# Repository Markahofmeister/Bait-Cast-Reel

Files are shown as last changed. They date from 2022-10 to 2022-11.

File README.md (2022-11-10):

# Bait-Cast-Reel

### A fishing-inspired spinoff of the original "Bop-It" Toy, completed for the University of Pittsburgh's ECE1895: Junior Design Course. 

File Structure: 
- `Bait-Cast-Reel-PCB` - Altium schematics and pcb desdign files for a 4-layered PCB
- `Bait-Cast-Reel-PCB-2l` - Altium schematics and pcb desdign files for a 2-layered PCB
- `diagrams-datasheets` - reference datasheets and pinout diagrams
- `fab` - .stl files of things to print/laser cut and PCB .step model
- `media` - images of the design process
- `software` - main src and supplementary testing sketches

The toy is shaped like a fishing rod and randomly selects one of three user inputs, which the user must complete within the allocated time window, else the user will lose the game. The three tangible user inputs - "Bait," "Cast," and "Reel," - use 3 different transducers to determine whether or not the user input was successful. 

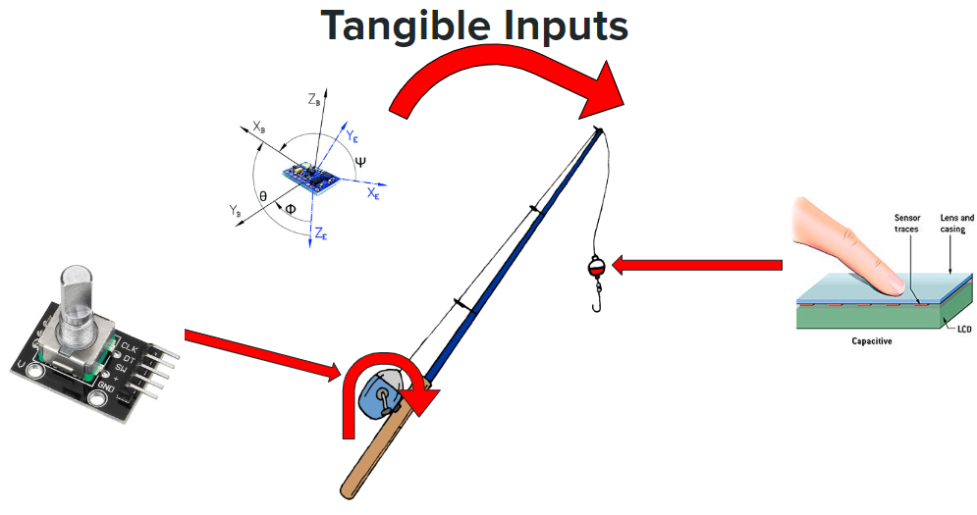
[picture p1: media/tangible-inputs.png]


## Firmware Flow

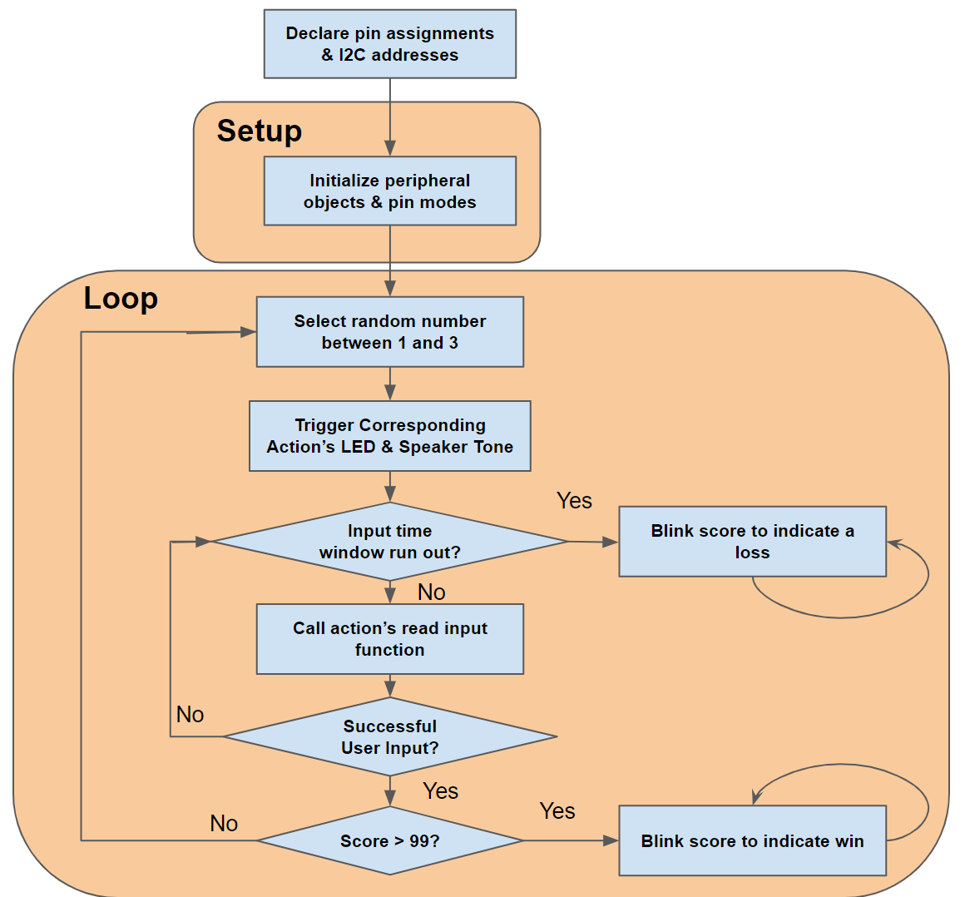
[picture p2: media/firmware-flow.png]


## System Diagram 

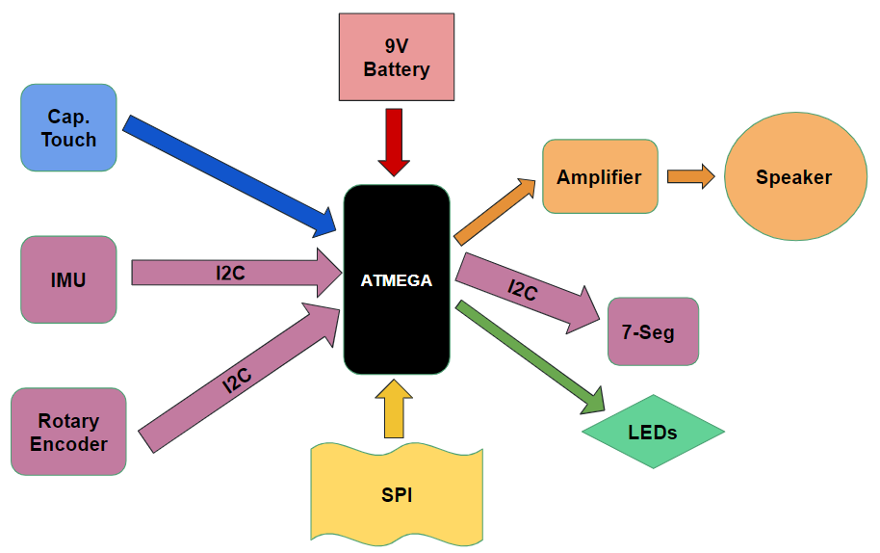
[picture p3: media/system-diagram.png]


## PCB

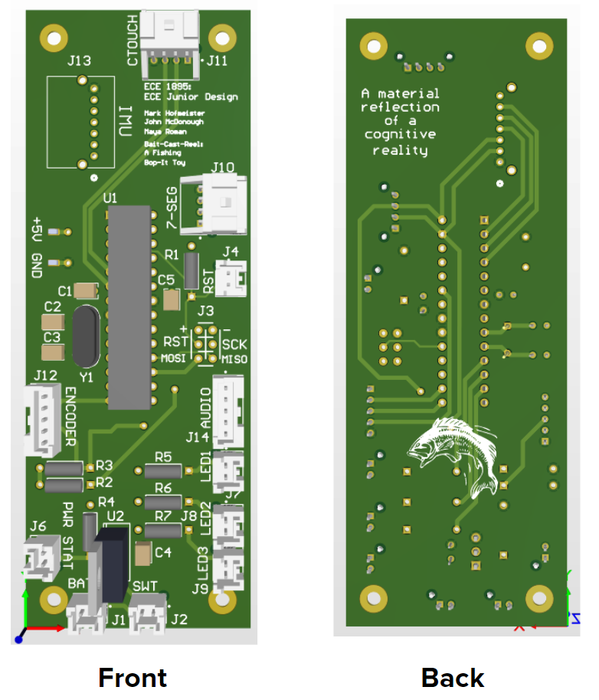
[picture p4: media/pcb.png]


## Enclosure 

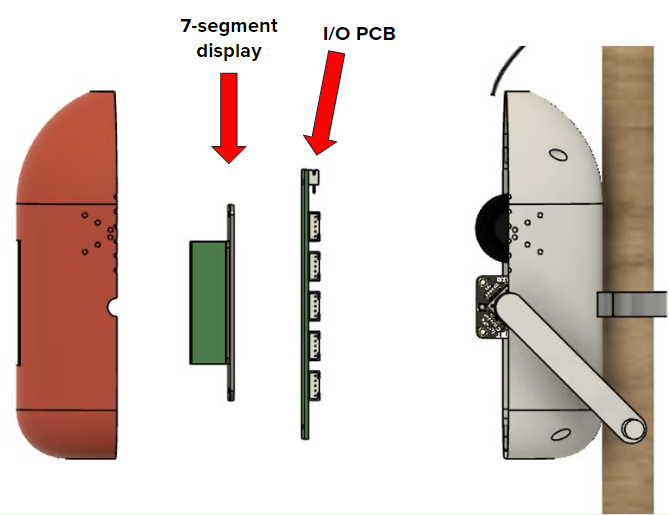
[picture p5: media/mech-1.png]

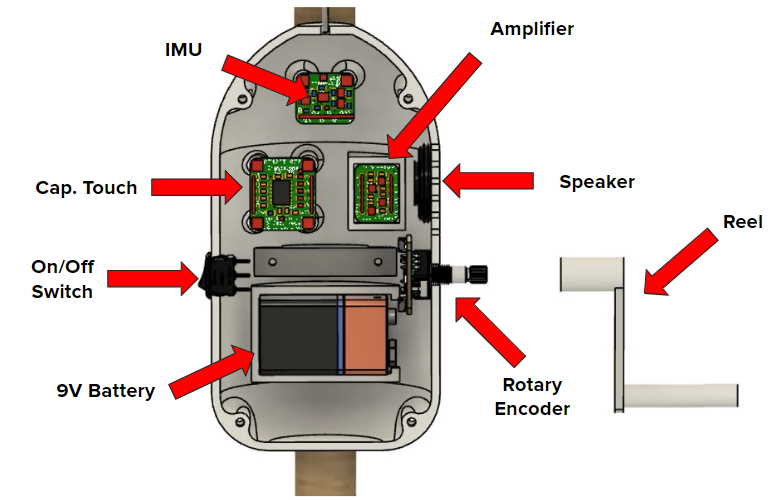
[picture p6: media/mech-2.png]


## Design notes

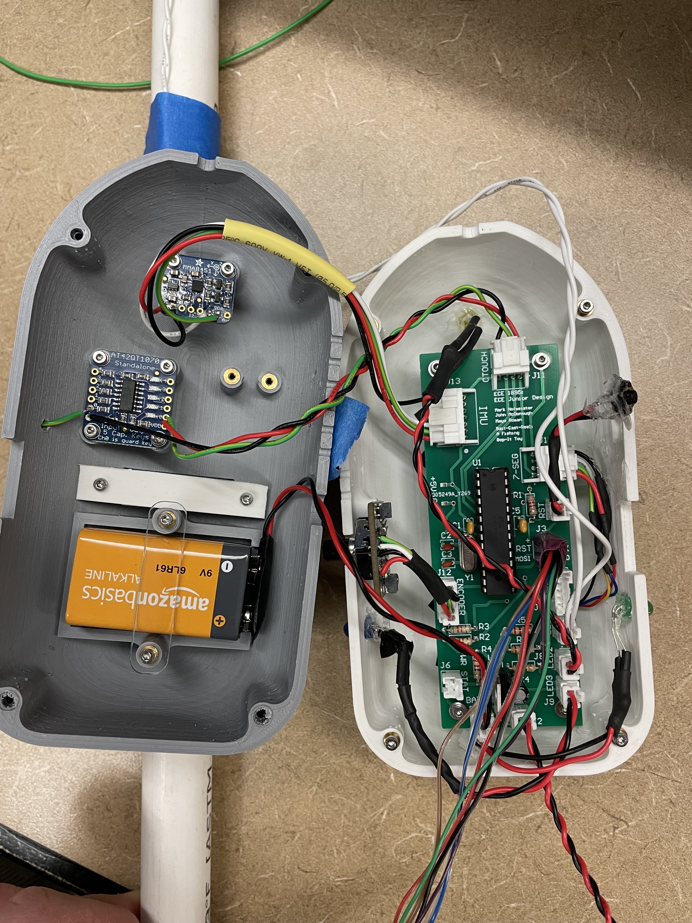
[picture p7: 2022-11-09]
media/enclosure-real.jpg

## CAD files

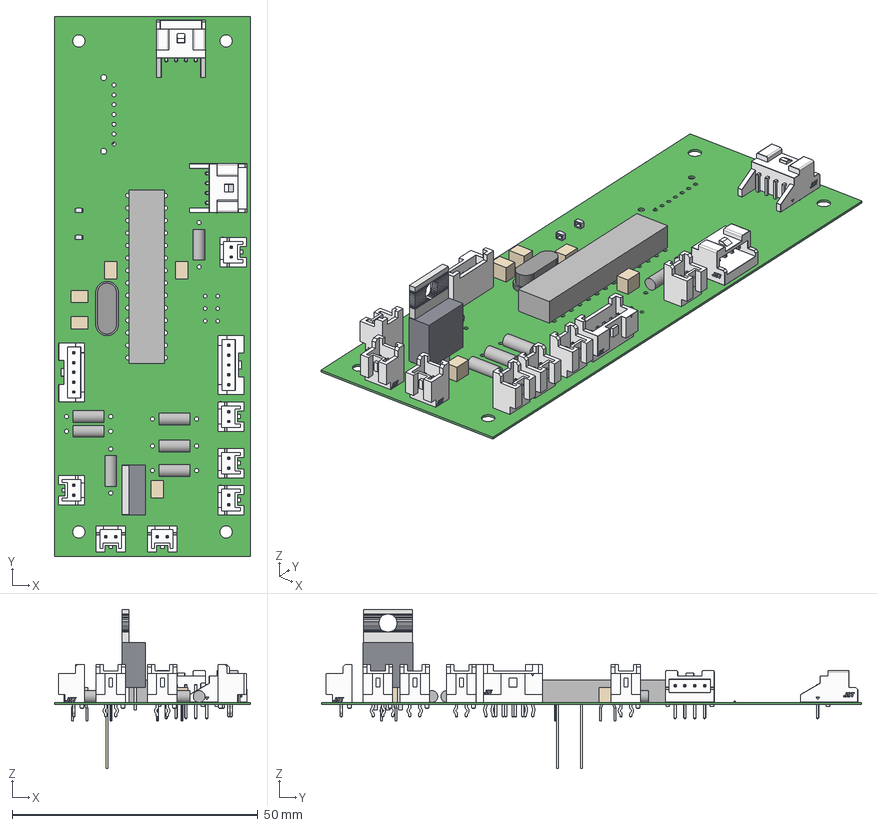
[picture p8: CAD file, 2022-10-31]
fab/main-IO-pcb.step
40.0 x 110.0 x 32.4 mm
terminal x 2
logo x 2
Extruded x 45
Pin1_Triangle x 2
JST x 2
B02B-PASK-1 x 7

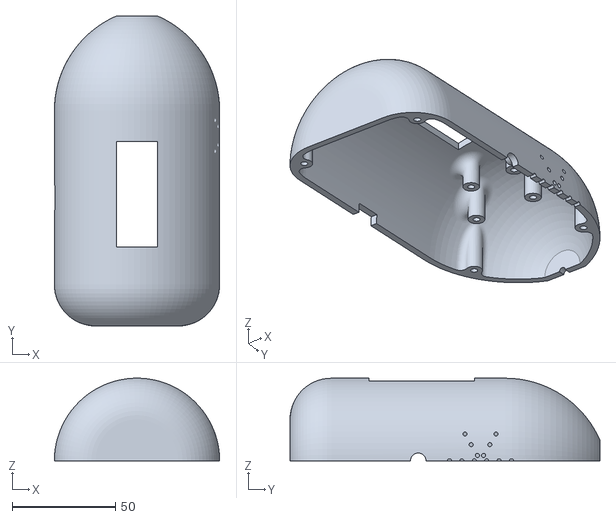
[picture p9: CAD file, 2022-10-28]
fab/mainboard_side.stl
80.0 x 150.0 x 40.0

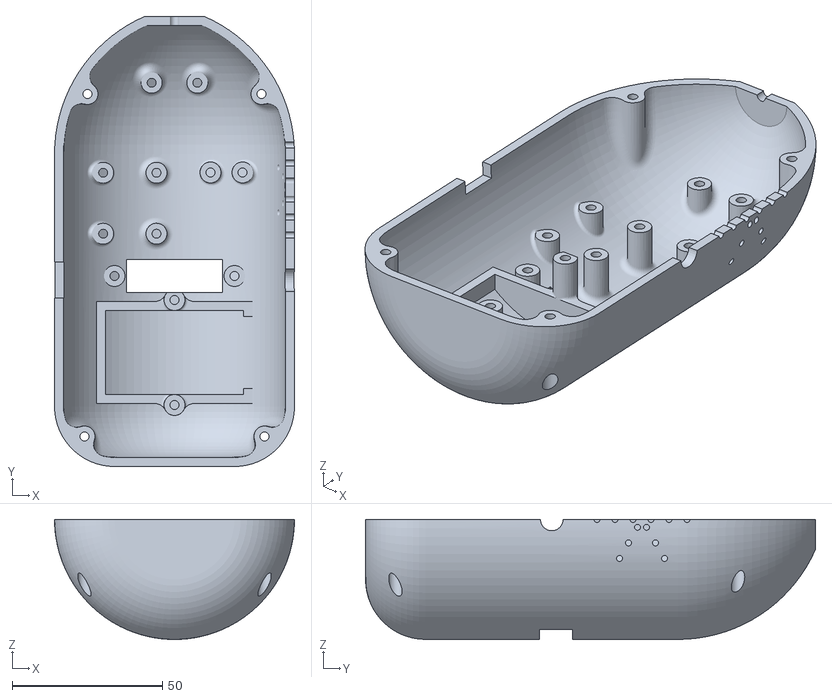
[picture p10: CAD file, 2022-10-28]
fab/battery_side.stl
80.0 x 150.0 x 40.0

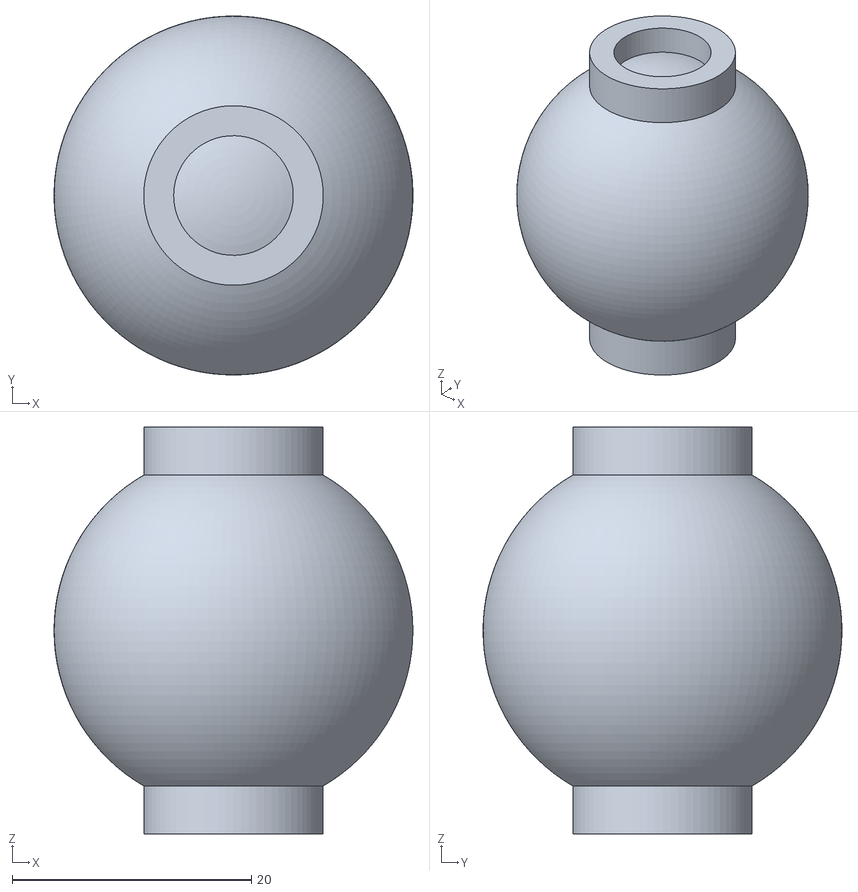
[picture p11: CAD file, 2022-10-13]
fab/Bobber.stl
30.0 x 30.0 x 34.0

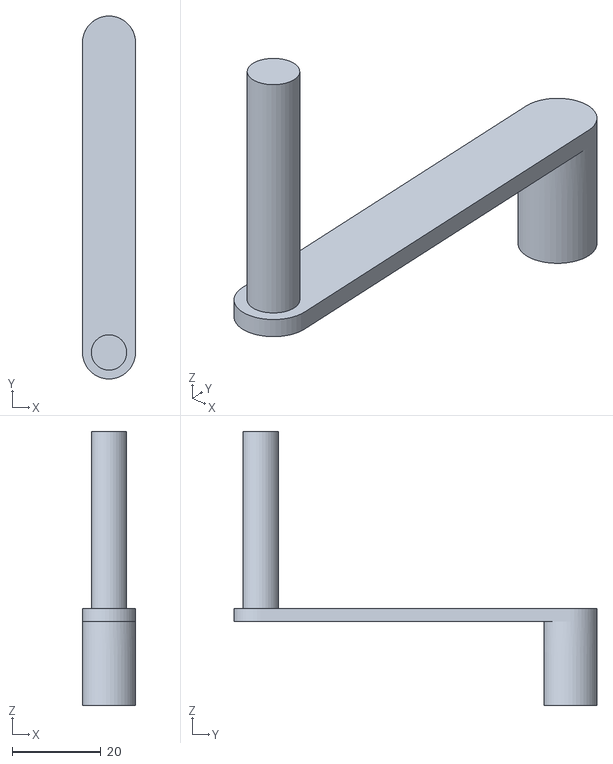
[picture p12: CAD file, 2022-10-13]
fab/crank.stl
12.0 x 82.0 x 62.0

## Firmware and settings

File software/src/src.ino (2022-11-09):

/**
 * File Name: src.ino 
 * Author: Mark Hofmeister, Maya Román, John McDonough
 * Created: 10/25/2022
 * Last Modified: 11/7/2022
 * 
 * Source code uploaded to Bait-Cast-Reel ATMEGA328p.
 */
 
#include "Adafruit_seesaw.h"            //Seesaw library, used for function calls to interact with encoder
#include <Adafruit_LEDBackpack.h>       //Used to communicate I2C to Adafruit's "backpack" for 7-seg display. 
#include <Adafruit_Sensor.h>
#include <Adafruit_MMA8451.h>
#include <math.h>

 /*
  * Define cap-touch global variables 
  */
    #define capTouchInput 3               //pin 5
    #define capTouchLED 5                 //pin 11
    
/*
 * Define IMU global variables & object
 */
    #define IMULED 6
    Adafruit_MMA8451 IMU = Adafruit_MMA8451();

/*
 * Define encoder global variables/object 
 */
    #define ENCODER_ADDR 0x36               //define I2C address of encoder as 0x36 
     
    #define SS_SWITCH 24                    //Not yet sure what this is required for
    //#define SS_NEOPIX 6                     //Required for the neopixel on the encoder board

    #define encoderLED 7
    
    Adafruit_seesaw encoder;                //Initialize encoder object and an integer to assign the position to 
    
    int32_t encoderPos = 0;                 //variable to store position, initialized to 0;
    int32_t lastPos = 0;                    //variable to store position from last encoder measurement, initialized to 0;
    int32_t lastFullRot = 0;                //variable to store to encoder position when it crosses the full rotation threshold
    int8_t fullTurn = 24;                   //One full rotation of the encoder is 24 steps. 

/*
 * Define 7-seg global variables & object
 */
    #define SEVSEG_ADDR 0x70                //define global I2C address of 7seg backpack 
    Adafruit_7segment sevSeg = Adafruit_7segment();   //initialize sevSeg object to interact with I2C backpack 
    int scoreCount = 0;                               //score to display and increment as user successfully inputs
  
  int inputWindow = 5000;                  //Start the input window length at 1000ms, which is the time allowed for a user input. Decreases with every iteration. 
  int inputWindowDec = 5;                  //integer to decrement the inputWindow by each iteration 

  /**
   * Define Audio global variables/pins
   */
   #define audioOut 9
   #define audioOut_LOW 10
   #define baitFreq 100
   #define castFreq 200
   #define reelFreq 300
   uint8_t audioDuration = 2000;   

void setup() {

  /*
   * Initialize cap. touch Pins
  */
      pinMode(capTouchInput, INPUT);
      pinMode(capTouchLED, OUTPUT);

  /*
   * Initialize IMU object & interrupts
  */
      pinMode(IMULED, OUTPUT);
      if(!IMU.begin()) {
        while(1);
      }
      IMU.setRange(MMA8451_RANGE_4_G);
 
  
  /*
   * Initialize encoder object & interrupts
  */
      Serial.println("Looking for encoder object");
      if (!encoder.begin(ENCODER_ADDR)) {
        Serial.println("Couldn't find encoder on default address, trying again.");
        while(1) delay(10);
      }
    
      encoder.pinMode(SS_SWITCH, INPUT_PULLUP);     //Is this pullup pin native to the encoder module itself? Will a bare ATMEGA vs. Uno have problems with this?
      encoderPos =  encoder.getEncoderPosition();
 
      pinMode(encoderLED, OUTPUT);

  /*
   * Initialize 7-seg object 
  */
      sevSeg.begin(SEVSEG_ADDR);
      sevSeg.print(scoreCount);
      sevSeg.writeDisplay();

  /**
   * Initialize audio pins
   */
      pinMode(audioOut, OUTPUT);
      pinMode(audioOut_LOW, OUTPUT);
      digitalWrite(audioOut_LOW, LOW);
  /**
   * Check LEDs and audio
   */
      digitalWrite(capTouchLED,HIGH); 
      digitalWrite(encoderLED,HIGH); 
      digitalWrite(IMULED,HIGH); 
//      tone(audioOut, baitFreq, audioDuration);
//      delay(audioDuration);
//      tone(audioOut, castFreq, audioDuration);
//      delay(audioDuration);
//      tone(audioOut, reelFreq, audioDuration);
      delay(2000);
      digitalWrite(capTouchLED,LOW); 
      digitalWrite(encoderLED,LOW); 
      digitalWrite(IMULED,LOW); 
}

void loop() {

  /*
   * Random number generation:
   * 1 - Bait - calls readBait() function
   * 2 - Cast - calls readCast() function
   * 3 - Reel - calls readReel() function
   */
  int randomNumber = floor(random(1,4));           //generates a random number in the range of 1 to 3  
   if(randomNumber == 1){
      //call cap_touch function
      digitalWrite(capTouchLED,HIGH);              // associated LED turns on 
      tone(audioOut, baitFreq, audioDuration);    //Play associated tone 
      delay(audioDuration);
      //send out audio command via talkie
      bool success_val = false;
      unsigned int current_time = millis(); //gets the number of milliseconds that program has been running

      while((millis()-current_time) <= inputWindow){//differencing time to see amount of time passed 
          success_val = readCapTouch();

          if(success_val){
            break;
          }
      }

      digitalWrite(capTouchLED, LOW); //turn LED off
      seven_seg(success_val);                              //Increment counter and display    
   } // end captouch if statement
   else if(randomNumber == 2){             //Cast It
      
      digitalWrite(IMULED, HIGH);

      tone(audioOut, castFreq, audioDuration);            //Play associated tone
      delay(audioDuration);
      unsigned int current_time2 = millis();
      bool success_val2 = false;

      while((millis()-current_time2) <= inputWindow){

        success_val2 = readIMU();
        
        if(success_val2){
          break;
        }
      }

      digitalWrite(IMULED, LOW);//turn off indicator led  
      seven_seg(success_val2);//Increment counter  
    } // end cast else if
    else if(randomNumber == 3){             //Reel It 
      
      digitalWrite(encoderLED, HIGH);
      tone(audioOut, reelFreq, audioDuration);          //Play associated tone
      delay(audioDuration);
      unsigned long current_time3 = millis();
      bool success_val3 = false;

      while((millis()-current_time3) <= inputWindow){
        success_val3 = readReel();

        if(success_val3){
          break;
        }
      }

      digitalWrite(encoderLED, LOW); //turn off indicator led  
      seven_seg(success_val3);      //Increment counter  
    } // end reel else if
      
    //default:            //Should never reach default, but you know. 
    else{
      while(1){
      }
    }

  inputWindow -= inputWindowDec;                  //Decrement inputWindow by inputWindowDec value (ms)
  
  delay(500);                                     //Delay 100ms before generating a new random action
}


/* readCapTouch()
 * Params: None
 * Retrns: Bool indicating whether the cap. touch was triggered
 * 
 */
bool readCapTouch(){
  int compare = 0;
  bool capOut; 
  
  while(compare < 1000){                
    if(digitalRead(capTouchInput) == LOW){
      capOut = true; 
    }else if(digitalRead(capTouchInput) == HIGH){
      capOut = false; 
      break;
    }
    delay(1);
    compare ++;
  }
  return capOut;
}

/* readReel()
 * Params: None
 * Retrns: Bool indicating whether the encoder was rotated one full rotation
 * 
 * Function to determine if the encoder was rotated through one full rotation since the last full rotation.
 * 
 * Also disregards negative rotation.
 */
bool readReel() {

  bool fullRotation = false;                    //initialize return flag to false
  encoderPos = encoder.getEncoderPosition();    //find new encoder position 

  if(encoderPos < lastPos) {      //prevent a backwards rotation
    //Serial.println("Enter backwards rotation conditional");
    encoderPos = lastPos;
  }

  int threshold = lastFullRot + fullTurn;     //Threshold to find a full rotation is the last full rotation threshold minus one full rotation
  
  if(encoderPos >= threshold) {               //If we have passed the threshold of rotation, set flag
    fullRotation = true;
    lastFullRot = encoderPos;               //Also update the lastFullRot
  }
  lastPos = encoderPos;                     
  
  return fullRotation;

}
/* readIMU()
 * Params: None
 * Retrns: Bool indicating whether the IMU has detected an input
 * 
 * Function to determine if the IMU has detected an input
 * 
 */
bool readIMU(){//function for IMU
  
  // Get a new sensor event
  sensors_event_t event; 
  IMU.getEvent(&event);
  uint8_t zaccel = event.acceleration.z;

  if(zaccel > 20){
    return true;
    }
  //no input detected
  return false;
}


/* seven_seg(success_val)
 * Params: bool to indicate a successul user input
 * Retrns: none
 * 
 * Function to write the output of the seven segment display depending on a successul user input. 
 * Increments if successul, displays score if not. 
 */
void seven_seg(bool success_val){ 
  if(success_val){                  
    scoreCount++;                             //increment count variable   
    sevSeg.print(scoreCount);
    sevSeg.writeDisplay();
    if (scoreCount >= 99) {                   //User has won. 
      int winDuration = 1000;
      while (1) {
        sevSeg.blinkRate(1);                  // Indicate winning with alternating between blinking and not blinking 
        tone(audioOut, 200, winDuration);   //Indicate that the user has won with a tone trill.
        delay(winDuration);
        tone(audioOut, 400, winDuration);
        delay(winDuration);
        tone(audioOut, 600, winDuration);
        delay(winDuration);
        tone(audioOut, 800, winDuration);
        delay(winDuration);
        tone(audioOut, 1000, winDuration);
        delay(winDuration);
        sevSeg.blinkRate(0);
        delay(2000);
      }
      deadLoop();                             //Should never reach here, but you know. 
    }
    delay(10);                                //Might have to adjust delays

  }
  else{                                   
    sevSeg.print(scoreCount);
    sevSeg.blinkRate(1);                      //Blinks the 7seg to indicate game over. 0 = no blink, 1,2,3 = varied blink rates. 
    sevSeg.writeDisplay();

    int failureDuration = 1000;
    
    tone(audioOut, 1000, failureDuration);   //Indicate that the user has failed with a tone trill.
    delay(failureDuration);
    tone(audioOut, 800, failureDuration);
    delay(failureDuration);
    tone(audioOut, 600, failureDuration);
    delay(failureDuration);
    tone(audioOut, 400, failureDuration);
    delay(failureDuration);
    tone(audioOut, 200, failureDuration);
    delay(failureDuration);
    
    deadLoop();
  }
}

/**
 * dead Loop to prevent incrementing of 7-seg and LED lighting after user failure
 * params: none
 * returns: none
 */
void deadLoop() {

  while(1) {
    
  }
  
}

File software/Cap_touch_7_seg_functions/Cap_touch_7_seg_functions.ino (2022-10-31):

//initializing libraries for talkie and 7-seg display
#include <Talkie.h>
#include <TalkieUtils.h>
#include <Vocab_US_Large.h>
#include <Vocab_Special.h>
#include <Adafruit_LEDBackpack.h>

//initializing pins for components 
#define cap_touch_input 3//pin 5
#define cap_touch_LED 5//pin 11

//initializing objects
Adafruit_7segment matrix = Adafruit_7segment();

static int count = 0;//will be incremented through function calls
static int timer = 10000;

void setup() {
  //setup code for 7-seg disp
   #ifndef __AVR_ATtiny85__
  Serial.begin(9600);
  Serial.println("7 Segment Backpack Test");
  #endif
  matrix.begin(0x70);

  //setup code for cap touch
  pinMode(cap_touch_input, INPUT);
  pinMode(cap_touch_LED, OUTPUT);

  //initializing 7-seg to zero
  matrix.print(count);
  matrix.writeDisplay();

}

void loop() {
  //initializing variables
  bool success_val;//will be used in function passes
  //test  
  success_val = cap_touch();
  seven_seg(success_val);

  timer = timer - 1000;
  if(timer == 0){
    timer = 10000;
  }
  delay(1000);//1 second delay


}

//Function Land 

void seven_seg(bool success_val){ //7-seg function - passes in a bool and static int
  if(success_val == true){//if tasks were successfull it will increment the count value and display the new value on 7-seg
    //incrementing count variable
    count++;
    matrix.print(count);
    matrix.writeDisplay();
    delay(10);//Might have to adjust delays

  }
  else{//if one of that tasks was not a success it will display the previous score count 
    matrix.print(count);
    matrix.writeDisplay();
    delay(10);//Might have to adjust delays
  }
}

bool cap_touch(){//cap-touch function passes out bool and brings in count variable;

  //initializations
  digitalWrite(cap_touch_LED,HIGH);//As soon as the function is called associated LED turns on 
  //send out audio command via talkie
  delay(timer);//have some type of delay after visual and audio commands are send out 
  
  if(digitalRead(cap_touch_input) == LOW){
     digitalWrite(cap_touch_LED,LOW);//turns off LED
    return true;
   }
   

  digitalWrite(cap_touch_LED,LOW);//turns off LED
  return false; 
}

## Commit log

2022-10-12 Add test A and interrupt things
2022-10-12 Add PCB to GH
    [Bait-Cast-Reel-PCB.PrjPcb, schem.SchDoc]
2022-10-13 Add preliminary CAD model stls
    [Bobber.stl, crank.stl, housing_battery_side.stl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]
2022-10-17 Add some IMU testing functions
2022-10-18 Added all components to single .SchDoc, wired input voltage
    [schem.SchDoc]
2022-10-18 Rename top-level schematic
    [ATMEGA328P.SchDoc, schem.SchDoc]
2022-10-18 Route SPI Interface
    [ATMEGA328P.SchDoc, peripherals.SchDoc]
2022-10-18 Finish wiring peripherals
    [ATMEGA328P.SchDoc, peripherals.SchDoc]
2022-10-19 Save PCBPrj.
    [Bait-Cast-Reel-PCB.PrjPcb]
2022-10-19 Begin PCB layout
    [ATMEGA328P.SchDoc, Bait-Cast-Reel-PCB.PrjPcb, pcb.PcbDoc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]
2022-10-19 More PCB routing
    [ATMEGA328P.SchDoc, pcb.PcbDoc, peripherals.SchDoc]
2022-10-19 Add decoupling caps, change to PWM audio outputs, fix SPI interface pin mapping
    [ATMEGA328P.SchDoc, Bait-Cast-Reel-PCB.PrjPcb, pcb.PcbDoc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]
2022-10-21 updated board layout
    finished (first pass at) routing the PCB
    [ATMEGA328P.SchDoc, Bait-Cast-Reel-PCB.PrjPcb, pcb.PcbDoc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]
2022-10-21 Remove speaker, add amplifier connector, change around a bit of routing.
    [ATMEGA328P.SchDoc, pcb.PcbDoc, peripherals.SchDoc]
2022-10-21 Decongest connectors
    [pcb.PcbDoc, peripherals.SchDoc]
2022-10-21 DRC pass. Add quote.
    [ATMEGA328P.SchDoc, pcb.PcbDoc]
2022-10-22 Final gerber sub
    [Bait-Cast-Reel-PCB.PrjPcb, pcb.PcbDoc]
2022-10-22 Add 2-layer PCB project files
    [ATMEGA328P.SchDoc, Bait-Cast-Reel-PCB-2l.PrjPcb, pcb.PcbDoc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]
2022-10-24 Add media and presentation
    [Bait-Cast-Reel-PCB-2l.PrjPcb]
2022-10-25 Rename CAD models --> fab
    [Bobber.stl, crank.stl, housing_battery_side.stl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]
2022-10-25 Add encoder initialization
2022-10-28 Replace fab files with updated housing.
    [battery_side.stl, housing_battery_side.stl, housing_mainboard_side.stl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]
2022-10-28 Added base encoder function. Need to solve backwards rotation
2022-10-28 I believe backwards rotation is fixed.
    [encoder-func.ino]
2022-10-30 add encoder function and init to source code. Opening PR.
2022-10-31 Add skeleton of cap touch switch case. Can we use pointers for a function call to save lines of for loop code?
2022-10-31 Add resistor values to schem.
    [ATMEGA328P.SchDoc, pcb.PcbDoc, peripherals.SchDoc]
2022-10-31 Add cable diagrams in .pptx and .pdf
2022-10-31 Add .step model of PCB to fab directory
    [main-IO-pcb.step]
2022-10-31 Implement cap. touch function while moving LED control into main loop
2022-11-07 IMU and encoder function work, IMU threshold needs adjust
2022-11-07 Add dead loop for user failure
    [src.ino]
2022-11-08 fixed capTouch function
    adjusted the capTouch function so it's less sensitive, adjusted some of the delay values
    [src.ino]
2022-11-09 Fix encoder function changes, remove Serial monitor, add tone() back in
    [src.ino]
